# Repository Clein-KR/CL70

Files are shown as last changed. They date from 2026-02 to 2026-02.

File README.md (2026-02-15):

# CL70

<br />

CL70은 제가 자작을 시도하며 처음 만들었던 키보드입니다.

아무것도 모르는 채로 시작하여 겪어야 했던 수 많은 시행 착오를 다른 분들은 최대한 줄였으면 하는 마음에 해당 키보드를 리메이크 하는 내용으로 [나만의 커스텀 커스텀 키보드 만들기 시리즈](https://www.notion.so/clein-kr/27f2e6fbea69806facf0daf639f351d5)를 노션에 연재해 두었으니 자작 키보드에 관심이 있으신 분들은 한 번 읽어 보시는 것을 추천 드립니다.

<br />
<br />

**Silver Top**

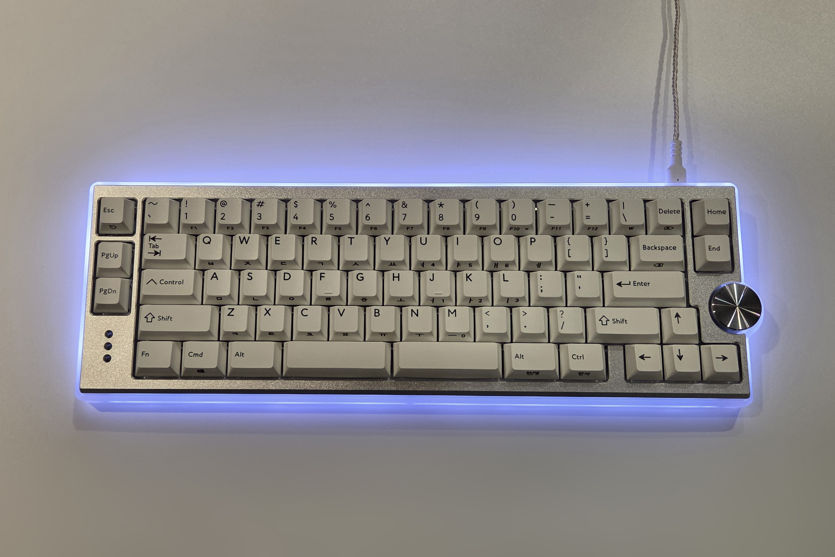
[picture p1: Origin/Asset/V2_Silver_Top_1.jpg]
V2 Silver Top 1

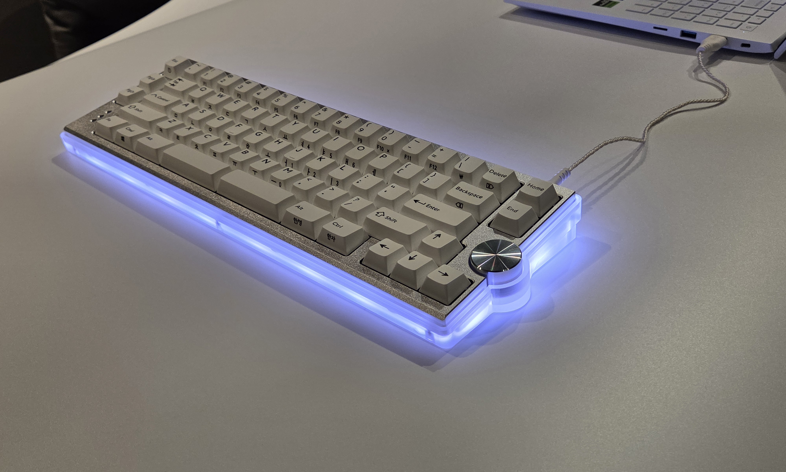
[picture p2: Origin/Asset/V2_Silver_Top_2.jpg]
V2 Silver Top 2


<br />

**Black Top**

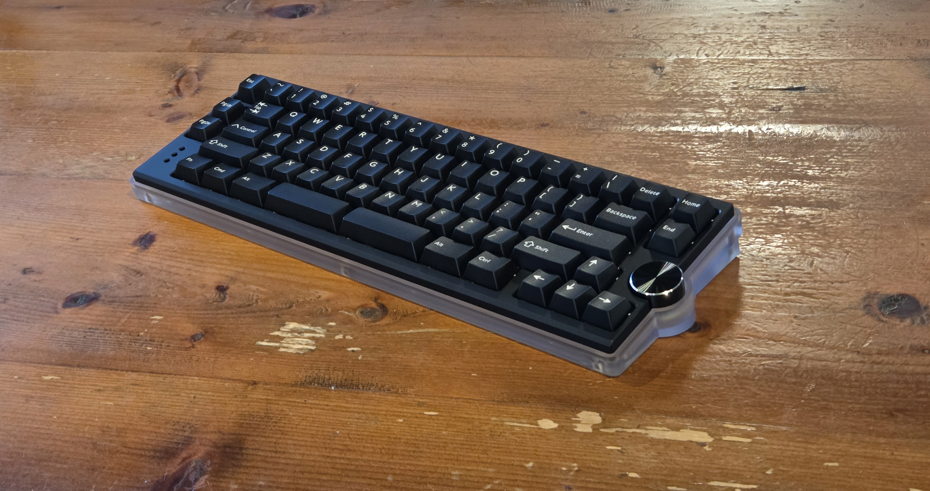
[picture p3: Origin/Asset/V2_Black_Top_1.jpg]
V2 Black Top 1

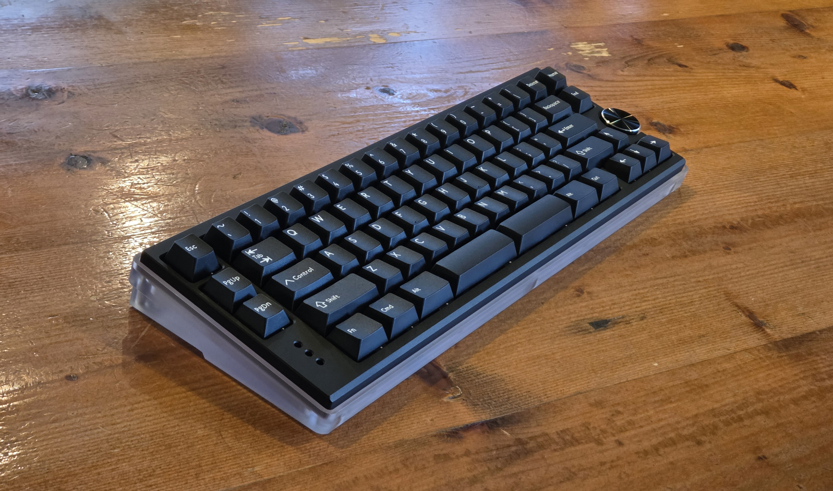
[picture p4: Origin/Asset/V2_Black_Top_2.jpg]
V2 Black Top 2


<br />
<br />

## Licence

<br />

작업물에 대한 영리적 목적의 사용 및 재배포는 허용하지 않으며, 비영리적 활동에만 사용 및 출처를 포함한 재배포를 허용합니다. 또한 작업물에 만약 오류나 문제가 있더라도 원작자는 이에 대해 어떠한 책임도 지지 않음을 미리 밝힙니다. 라이선스 전문은 [여기](./LICENCE)에서 보실 수 있습니다.

<br />
<br />

© 2026 [Clein](https://github.com/Clein-KR) All Rights Reserved. Licensed under [CC BY-NC 4.0](https://creativecommons.org/licenses/by-nc/4.0/)

<br />

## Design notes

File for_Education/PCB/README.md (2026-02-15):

# CL70 PCB for Education

<br />

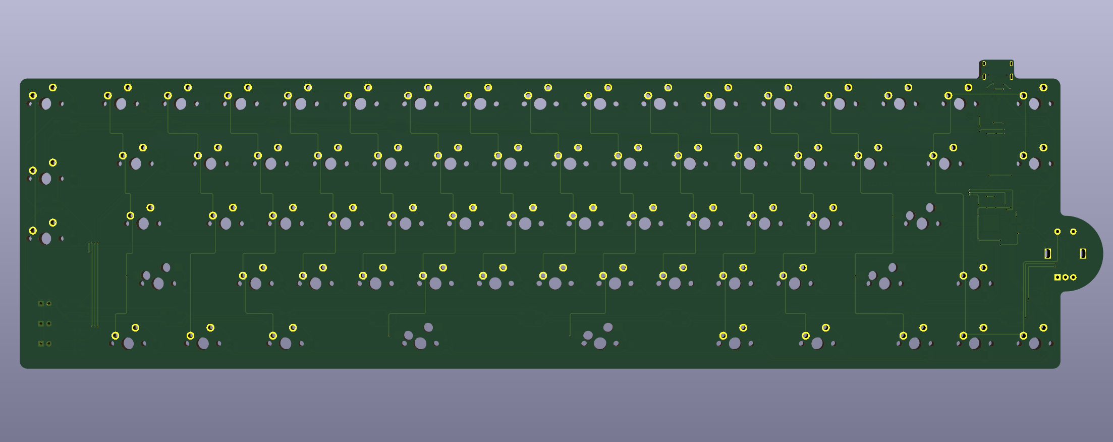
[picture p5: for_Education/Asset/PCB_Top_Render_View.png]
PCB Render Top View

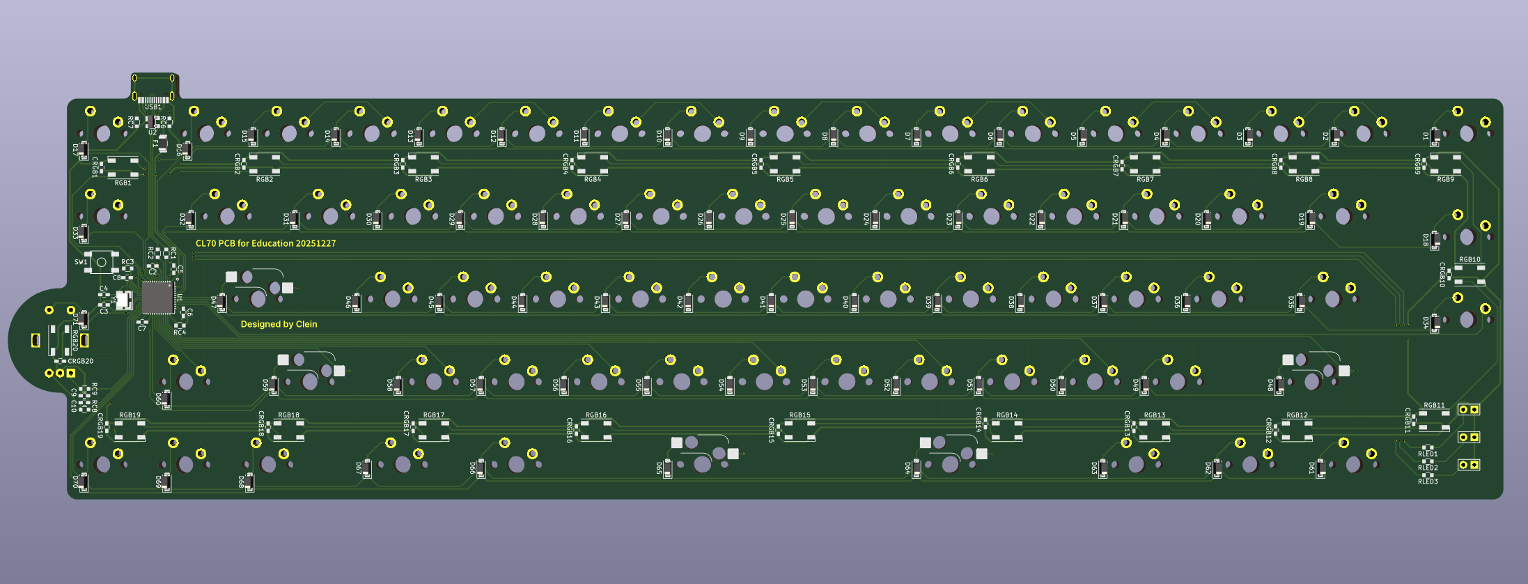
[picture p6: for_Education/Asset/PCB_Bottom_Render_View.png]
PCB Render Bottom View


<br />
<br />

## Licence

<br />

해당 프로젝트는 [ai03](https://github.com/ai03-2725) 님의 [KBD8X-MKII-PCB](https://github.com/ai03-2725/KBD8X-MKII-PCB) 프로젝트와 [Joe Scotto](https://github.com/joe-scotto) 님의 [ScottoKeebs](https://github.com/joe-scotto/scottokeebs) 프로젝트를 기반으로 만들어졌습니다. 해당 프로젝트를 활용한 수정, 복제, 배포 등의 활동은 저작자 표시와 함께 비영리적인 목적에 한해서만 가능하며, 라이선스 전문은 [여기](./LICENCE)에서 보실 수 있습니다.

<br />



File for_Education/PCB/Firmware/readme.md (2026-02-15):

# clein/cl70/for_education

clein/cl70/for_education

*A short description of the keyboard/project*

* Keyboard Maintainer: [Clein](https://github.com/Clein)
* Hardware Supported: *The PCBs, controllers supported*
* Hardware Availability: *Links to where you can find this hardware*

Make example for this keyboard (after setting up your build environment):

    make clein/cl70/for_education:default

Flashing example for this keyboard:

    make clein/cl70/for_education:default:flash

See the [build environment setup](https://docs.qmk.fm/#/getting_started_build_tools) and the [make instructions](https://docs.qmk.fm/#/getting_started_make_guide) for more information. Brand new to QMK? Start with our [Complete Newbs Guide](https://docs.qmk.fm/#/newbs).

## Bootloader

Enter the bootloader in 3 ways:

* **Bootmagic reset**: Hold down the key at (0,0) in the matrix (usually the top left key or Escape) and plug in the keyboard
* **Physical reset button**: Briefly press the button on the back of the PCB - some may have pads you must short instead
* **Keycode in layout**: Press the key mapped to `QK_BOOT` if it is available

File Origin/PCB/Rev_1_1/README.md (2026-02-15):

# CL70 PCB

<br />

[CL70 PCB Rev 1.0](/Origin/PCB/Rev_1_0/)에서 6u 스페이스바 단일 배열로 변경된 버전입니다. 이외 변경 사항은 없습니다.

<br />

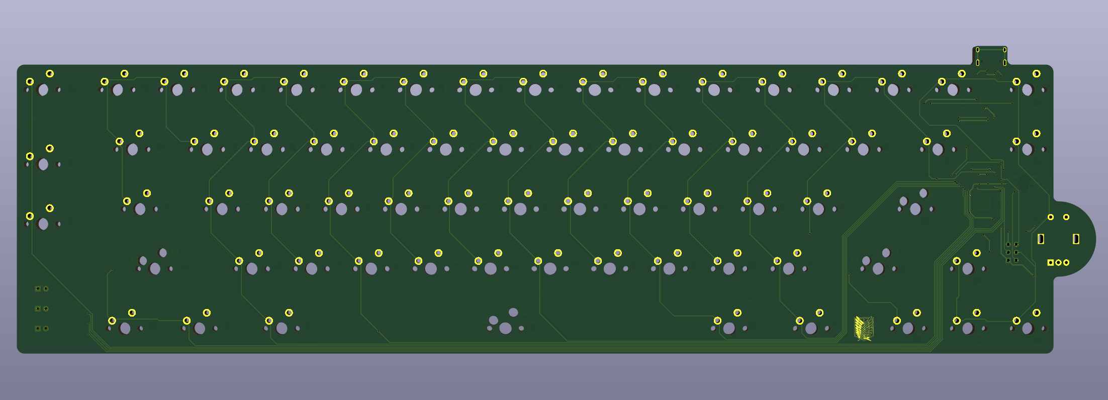
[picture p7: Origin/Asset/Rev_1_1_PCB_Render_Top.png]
PCB Rendering Top View

PCB Rendering Bottom View

<br />
<br />

## Licence

<br />

해당 프로젝트는 [ai03](https://github.com/ai03-2725) 님의 [KBD8X-MKII-PCB](https://github.com/ai03-2725/KBD8X-MKII-PCB) 프로젝트와 [Joe Scotto](https://github.com/joe-scotto) 님의 [ScottoKeebs](https://github.com/joe-scotto/scottokeebs) 프로젝트를 기반으로 만들어졌습니다. 해당 프로젝트를 활용한 수정, 복제, 배포 등의 활동은 저작자 표시와 함께 비영리적인 목적에 한해서만 가능하며, 라이선스 전문은 [여기](./LICENCE)에서 보실 수 있습니다.

<br />



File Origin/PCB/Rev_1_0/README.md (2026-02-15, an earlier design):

# CL70 PCB

<br />

해당 PCB의 프로토타입은 [PCBWay](https://www.pcbway.com/)를 통해 제작되었습니다.

<br />

PCB Rendering Top View
PCB Rendering Bottom View

<br />

PCB Prototype Top View
PCB Prototype Bottom View

<br />

아래는 적용된 옵션입니다.

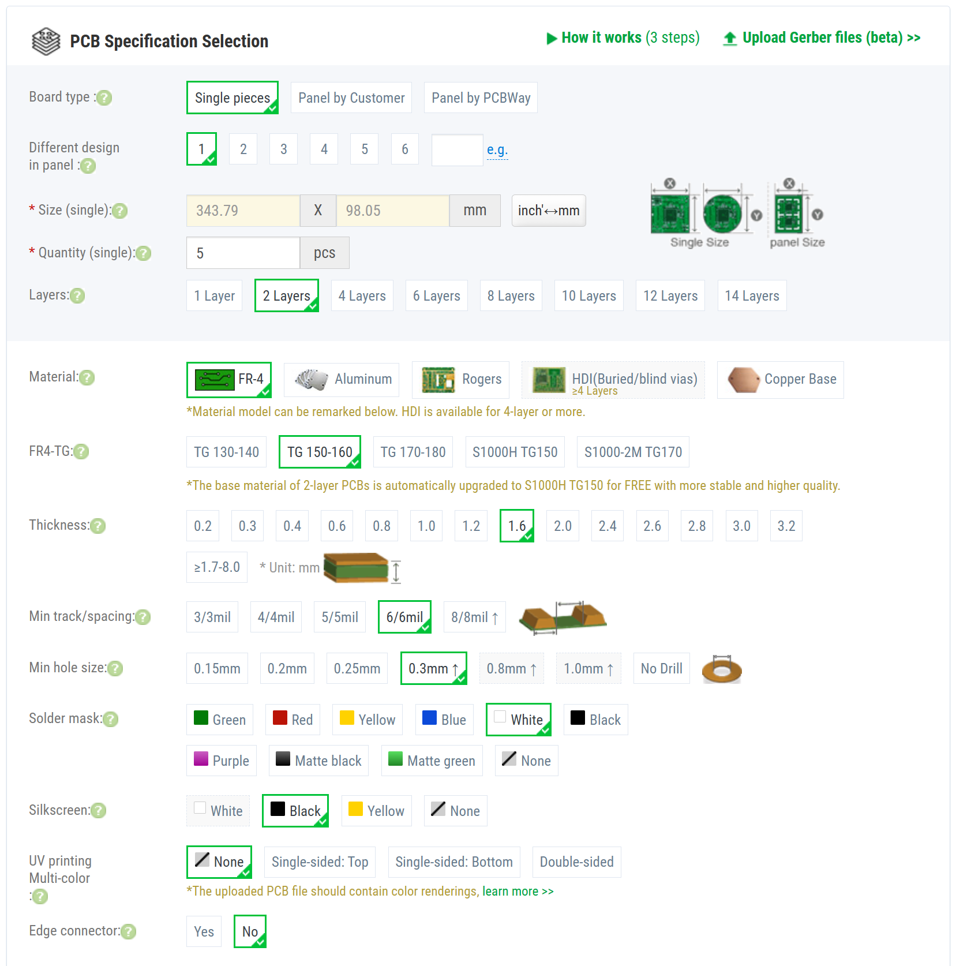
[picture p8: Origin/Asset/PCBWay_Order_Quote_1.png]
Options applied to the PCB prototype 1

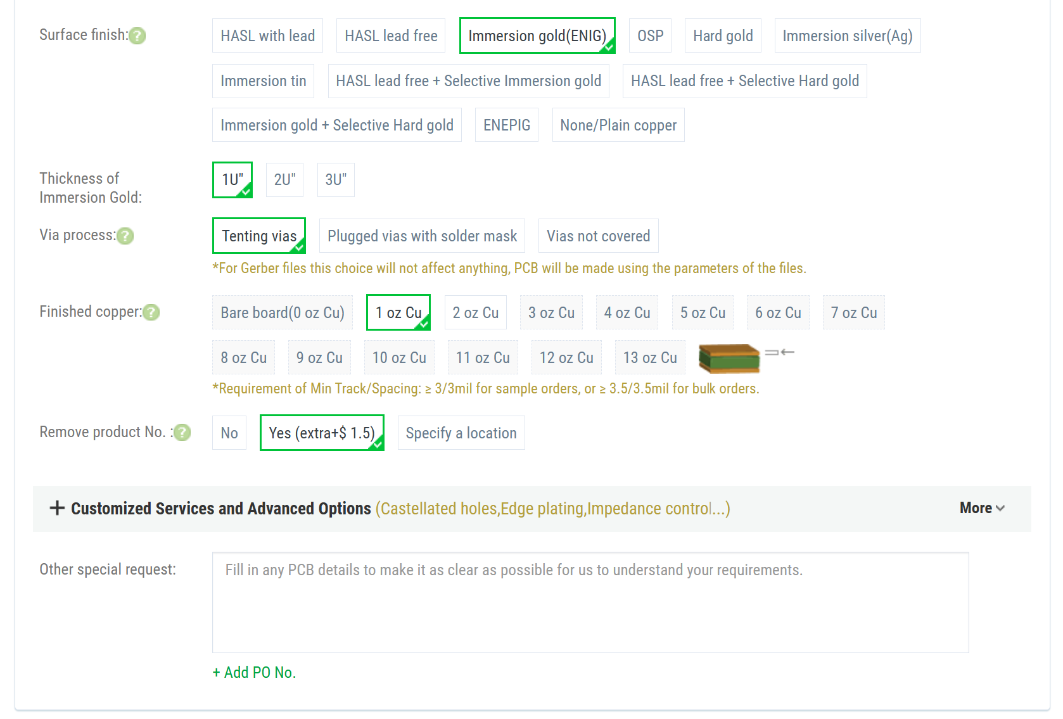
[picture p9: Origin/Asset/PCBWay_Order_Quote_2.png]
Options applied to the PCB prototype 2


<br />
<br />

## Licence

<br />

해당 프로젝트는 [ai03](https://github.com/ai03-2725) 님의 [KBD8X-MKII-PCB](https://github.com/ai03-2725/KBD8X-MKII-PCB) 프로젝트와 [Joe Scotto](https://github.com/joe-scotto) 님의 [ScottoKeebs](https://github.com/joe-scotto/scottokeebs) 프로젝트를 기반으로 만들어졌습니다. 해당 프로젝트를 활용한 수정, 복제, 배포 등의 활동은 저작자 표시와 함께 비영리적인 목적에 한해서만 가능하며, 라이선스 전문은 [여기](./LICENCE)에서 보실 수 있습니다.

<br />



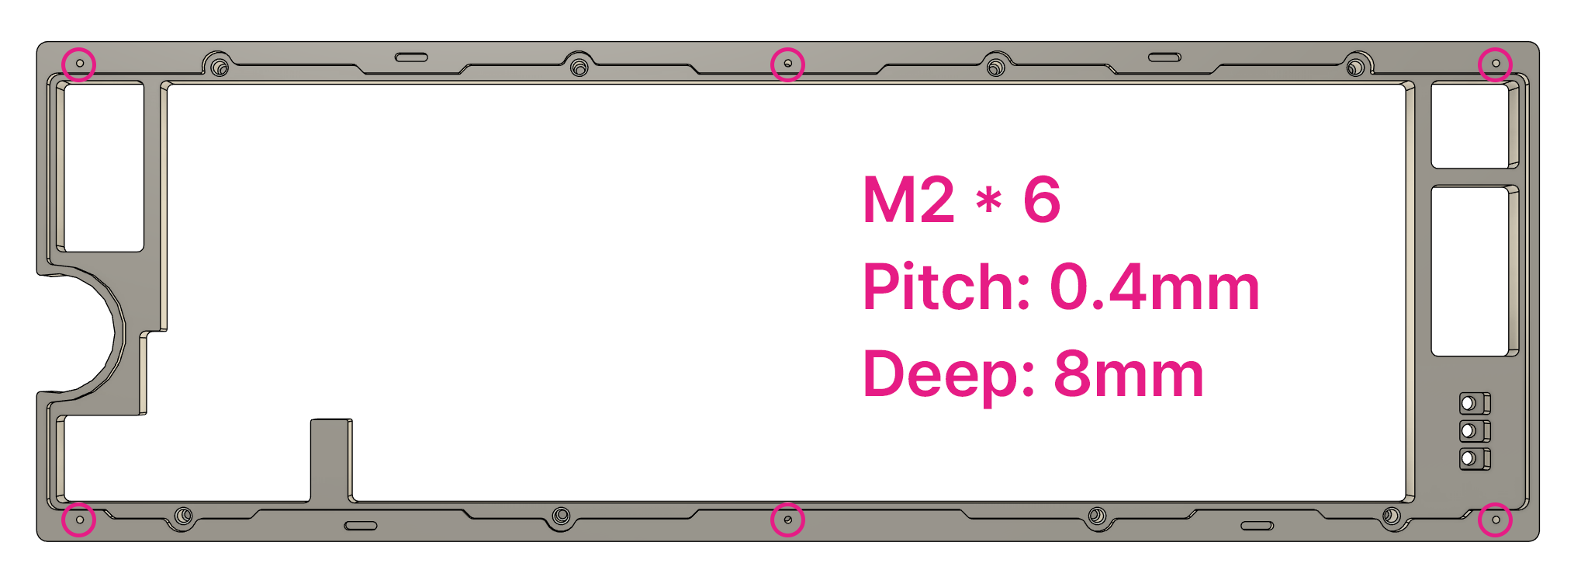
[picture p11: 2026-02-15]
for_Education/Case/CL70_EDU_TopCase_TappedHole.png

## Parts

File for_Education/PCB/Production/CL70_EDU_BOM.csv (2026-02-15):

Item # | *Designator | *Qty | Manufacturer | *Mfg Part # | LCSC Part # | Description / Value | *Package/Footprint | Pins | Your Instructions / Notes
1 | C6,C7,C8,CRGB1,CRGB2,CRGB3,CRGB4,CRGB5,CRGB6,CRGB7,CRGB8,CRGB9,CRGB10,CRGB11,CRGB12,CRGB13,CRGB14,CRGB15,CRGB16,CRGB17,CRGB18,CRGB19,CRGB20 | 23 | YAGEO | CC0603JRX7R7BB104 | C109474 | Capacitor, Ceramic, 0603 | C_0603 | 2 | 0.1uF 20% ≥15V X5R/X7R
2 | C5 | 1 | HRE | CGA0603X5R106M160JT | C6119814 | Capacitor, Ceramic, 0603 | C_0603 | 2 | 10uF 20% ≥15V X5R/X7R
3 | C2 | 1 | HRE | CGA0603X5R105K160JT | C6119849 | Capacitor, Ceramic, 0603 | C_0603 | 2 | 1uF 20% ≥15V X5R/X7R
4 | C3,C4 | 2 | KEMET | C0603C220J4GAC7867 | C561800 | Capacitor, Ceramic, 0603 | C_0603 | 2 | 22pF 5% ≥15V C0G
5 | D1,D2,D3,D4,D5,D6,D7,D8,D9,D10,D11,D12,D13,D14,D15,D16,D17,D18,D19,D20,D21,D22,D23,D24,D25,D26,D27,D28,D29,D30,D31,D32,D33,D34,D35,D36,D37,D38,D39,D40,D41,D42,D43,D44,D45,D46,D47,D48,D49,D50,D51,D52,D53,D54,D55,D56,D57,D58,D59,D60,D61,D62,D63,D64,D65,D66,D67,D68,D69,D70,D71 | 71 | Slkor(SLKORMICRO Elec.) | 1N4148W | C444720 | Diode, SOD-123 | D_SOD-123 | 2 | Generic
6 | F1 | 1 | BHFUSE | BSMD1206-050-16V | C883124 | Polyfuse, 1206 | Fuse_SMD1206_Wave | 2 | 500mA ≥15V 500mA_Hold 1A_Trip
7 | RC4,RLED1,RLED2,RLED3 | 4 | YAGEO | RC0603FR-071KL | C22548 | Resistor, Generic, 0603 | R_0603 | 2 | 1k 1%
8 | RC3,RC8,RC9 | 3 | YAGEO | RC0603FR-0710KL | C98220 | Resistor, Generic, 0603 | R_0603 | 2 | 10k 1%
9 | RC1,RC2 | 2 | YAGEO | RC0603FR-0722RL | C107701 | Resistor, Generic, 0603 | R_0603 | 2 | 22 1%
10 | RC6,RC7 | 2 | YAGEO | RC0603FR-075K1L | C105580 | Resistor, Generic, 0603 | R_0603 | 2 | 5.1k 1%
11 | RGB1,RGB2,RGB3,RGB4,RGB5,RGB6,RGB7,RGB8,RGB9,RGB10,RGB11,RGB12,RGB13,RGB14,RGB15,RGB16,RGB17,RGB18,RGB19,RGB20 | 20 | Worldsemi | WS2812B-V5/W | C2874885 | RGB LED, 5050 | LED_WS2812B-PLCC4 | 4 | WS2812B
12 | SW1 | 1 | ALPSALPINE | SKQGABE010 | C115351 | Push button | SKQG-1155865 | 4 | SMT 5.2 x 5.2 x 1.5mm
13 | U1 | 1 | MICROCHIP | ATMEGA32U4-MU | C112161 | ATmega32U4-MU | QFN-44-1EP_7x7mm_Pitch0.5mm | 45 | ATmega32U4-MU
14 | U2 | 1 | Nexperia | PRTR5V0U2X,215 | C12333 | ESD Protection IC | SOT143B | 4 | PRTR5V0U2X
15 | USB1 | 1 | Korean Hroparts Elec | TYPE-C-31-M-12 | C165948 | USB Type-C Connector | HRO-TYPE-C-31-M-12-Assembly | 16 | HRO-TYPE-C-31-M-12
16 | Y1 | 1 | Huiyuan crystal | HY16MSMD3225OB1R30 | C7275098 | Crystal, 3.2 x 2.5mm (3225-4) | Crystal_SMD_3225-4pin_3.2x2.5mm | 4 | 16MHz

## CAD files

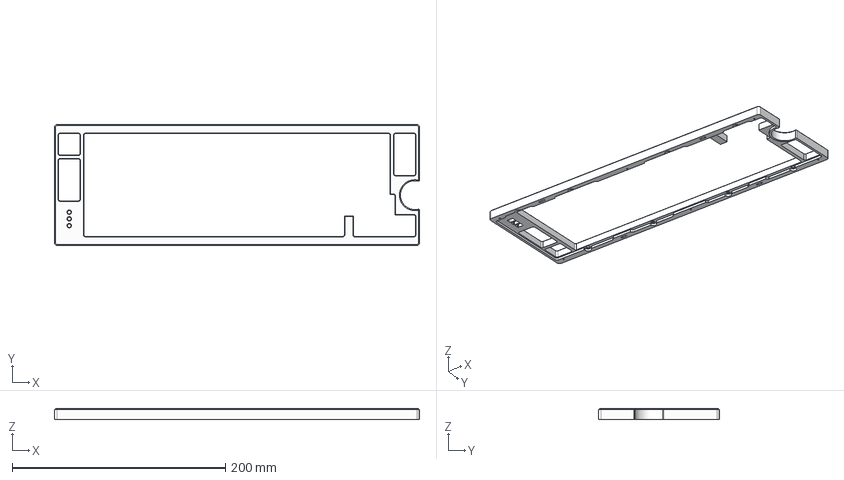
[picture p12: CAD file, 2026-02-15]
for_Education/Case/CL70_EDU_TopCase.step
342.0 x 113.5 x 10.0 mm

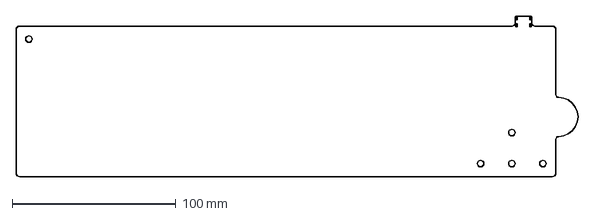
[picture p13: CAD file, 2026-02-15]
for_Education/PCB/Guide/PCB_OUTLINE.dxf
344.3 x 98.1 mm

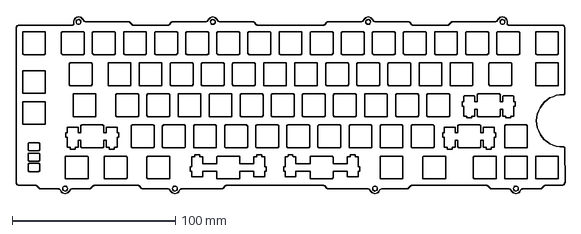
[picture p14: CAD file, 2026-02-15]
for_Education/Plate/CL70_Plate.dxf
336.3 x 108.5 mm

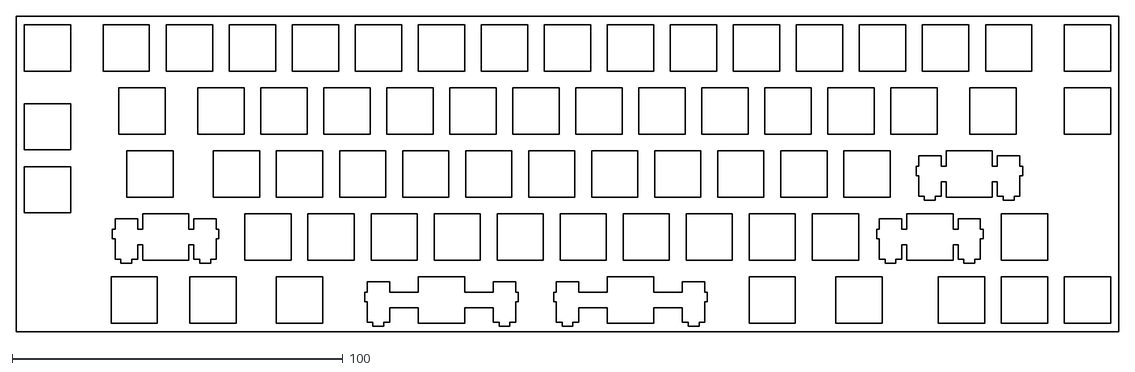
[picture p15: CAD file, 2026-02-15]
for_Education/Plate/References/builder.swillkb.com.dxf
333.4 x 95.2

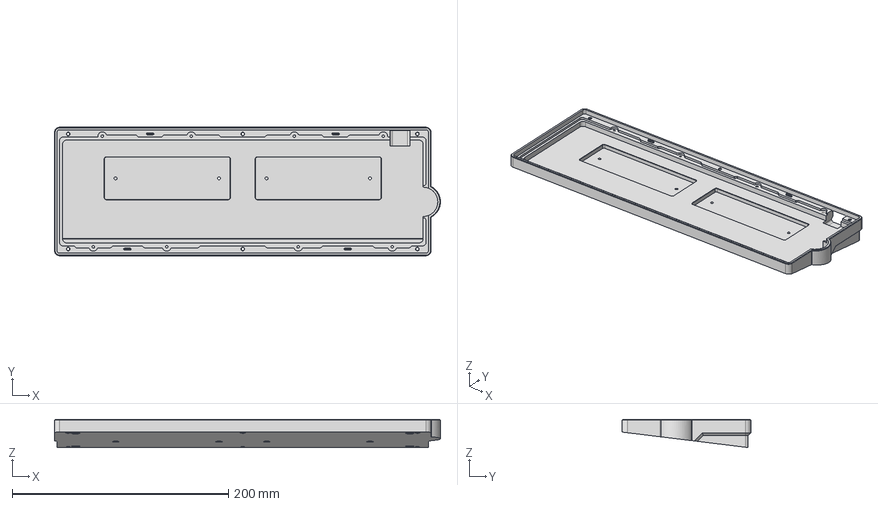
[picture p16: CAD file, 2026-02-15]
Origin/Case/CL70_BottomCase_V2.step
356.7 x 118.9 x 26.0 mm

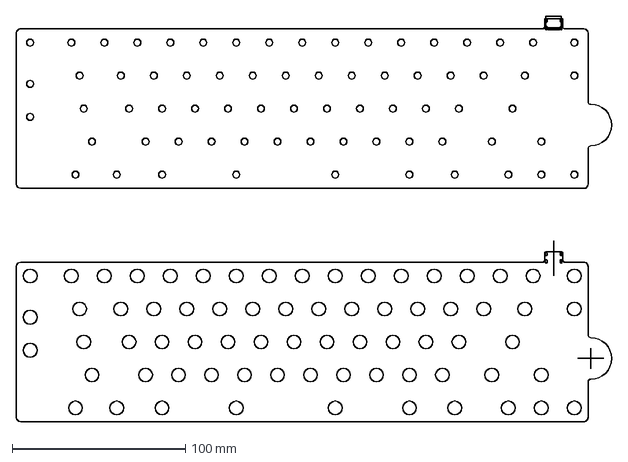
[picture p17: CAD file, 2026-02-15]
Origin/PCB/Rev_1_1/Guide/PCB_OUTLINE.dxf
343.8 x 234.1 mm

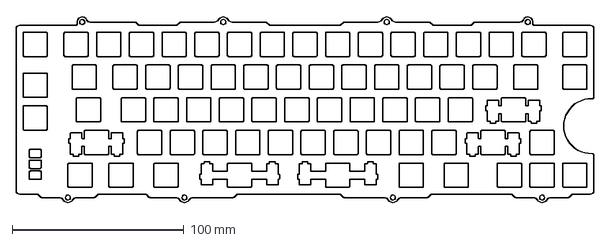
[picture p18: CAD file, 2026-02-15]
Origin/Plate/CL70_Plate_3u_Split.dxf
336.5 x 108.5 mm

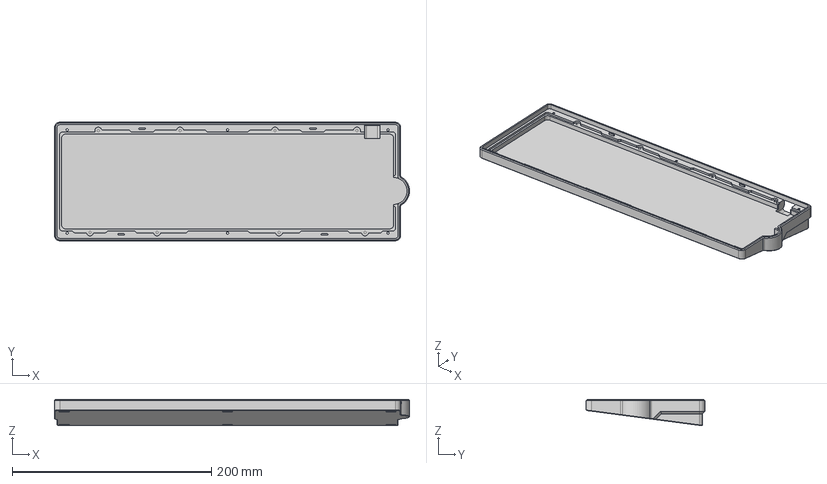
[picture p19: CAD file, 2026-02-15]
for_Education/Case/CL70_EDU_BottomCase.step
356.4 x 119.1 x 26.5 mm

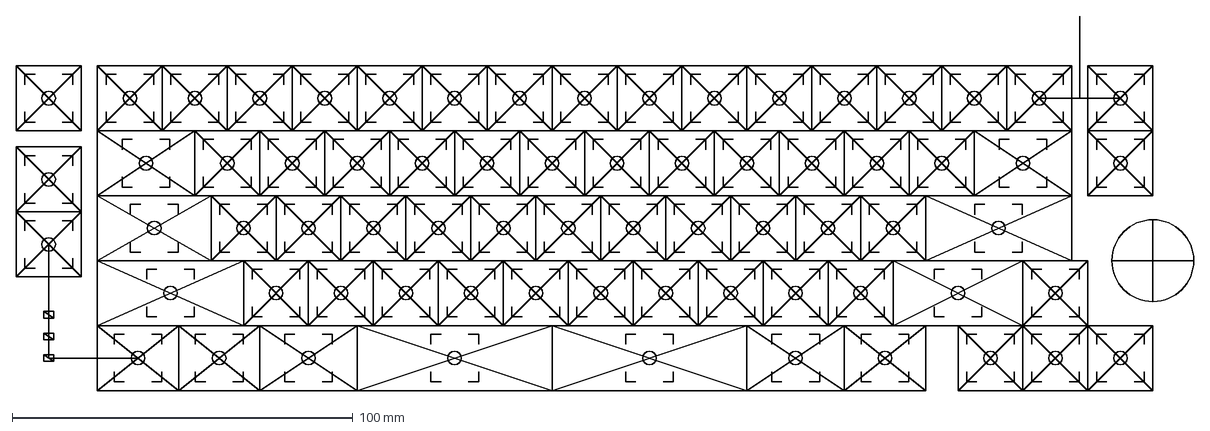
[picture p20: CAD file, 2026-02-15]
for_Education/PCB/Guide/PCB_GUIDELINE.dxf
345.4 x 109.7 mm

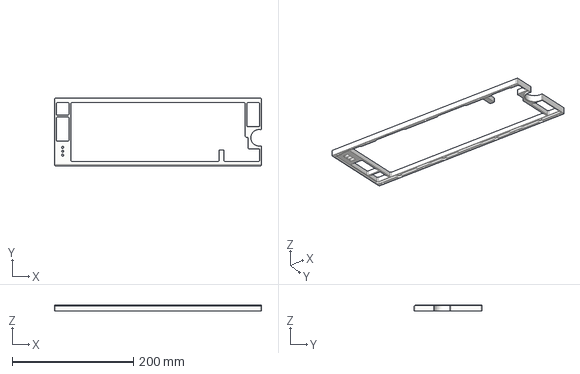
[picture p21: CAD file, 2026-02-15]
Origin/Case/CL70_TopCase_V2.step
341.4 x 112.3 x 10.0 mm

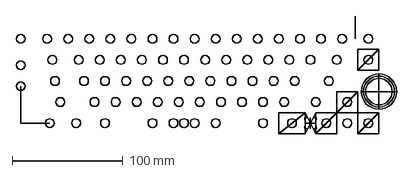
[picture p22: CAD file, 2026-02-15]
Origin/PCB/Rev_1_1/Guide/PCB_GUIDELINE.dxf
343.9 x 106.1 mm

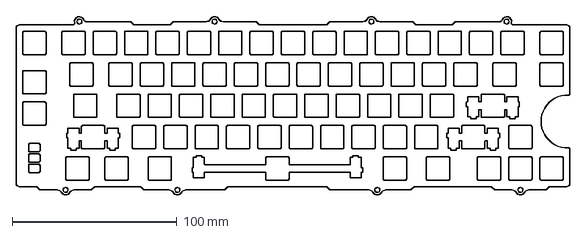
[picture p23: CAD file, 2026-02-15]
Origin/Plate/CL70_Plate_6u.dxf
336.5 x 108.5 mm

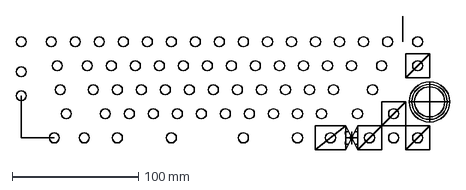
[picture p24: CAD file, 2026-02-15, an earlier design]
Origin/PCB/Rev_1_0/Guide/PCB_GUIDELINE.dxf
343.9 x 106.1 mm

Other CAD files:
Origin/Case/CL70_BottomCase_V2_InsertNuts.step
Origin/Case/CL70_TopCase_V2_TappedHole.step
Origin/Case/CL70_BottomCase_V2_TappedHole.step
Origin/Case/CL70_BottomCase_V2_NonWeight.step
Origin/PCB/Rev_1_0/Guide/PCB_GUIDELINE.dwg
Origin/PCB/Rev_1_0/Guide/PCB_OUTLINE.dwg
Origin/PCB/Rev_1_1/Guide/PCB_GUIDELINE.dwg
Origin/PCB/Rev_1_1/Guide/PCB_OUTLINE.dwg
Origin/Plate/CL70_Plate_3u_Split.dwg
Origin/Plate/CL70_Plate_6u.dwg
for_Education/Case/CL70_EDU.f3d
for_Education/PCB/Guide/PCB_GUIDELINE.dwg
for_Education/PCB/Guide/PCB_OUTLINE.dwg
for_Education/Plate/CL70_Plate.dwg

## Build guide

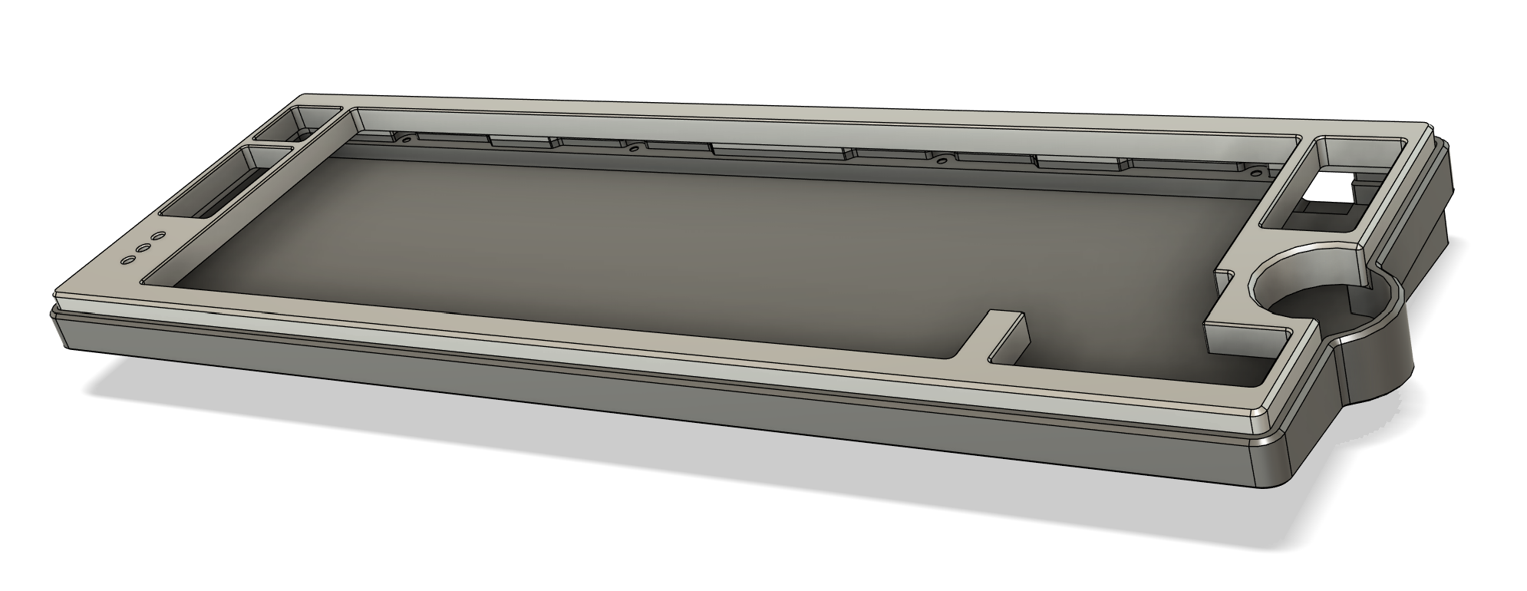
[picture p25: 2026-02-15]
for_Education/Case/CL70_EDU_AssemblyTest_1.png

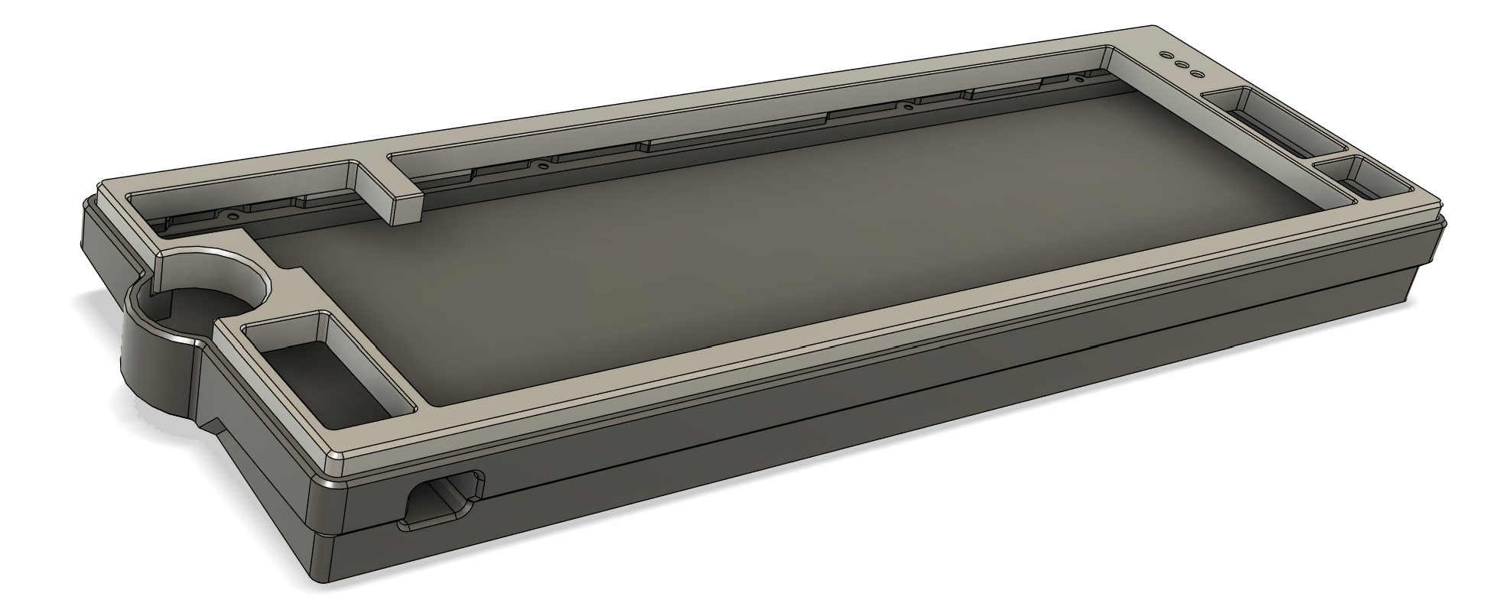
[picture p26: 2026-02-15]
for_Education/Case/CL70_EDU_AssemblyTest_3.png

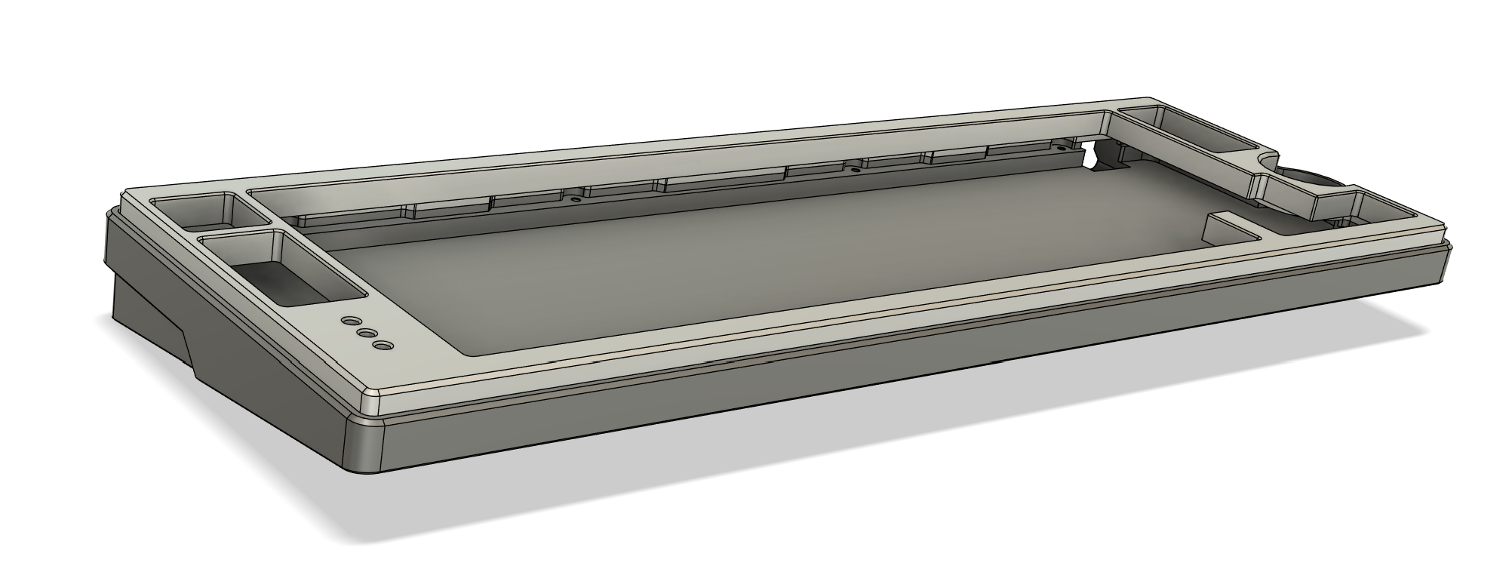
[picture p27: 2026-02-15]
for_Education/Case/CL70_EDU_AssemblyTest_2.png

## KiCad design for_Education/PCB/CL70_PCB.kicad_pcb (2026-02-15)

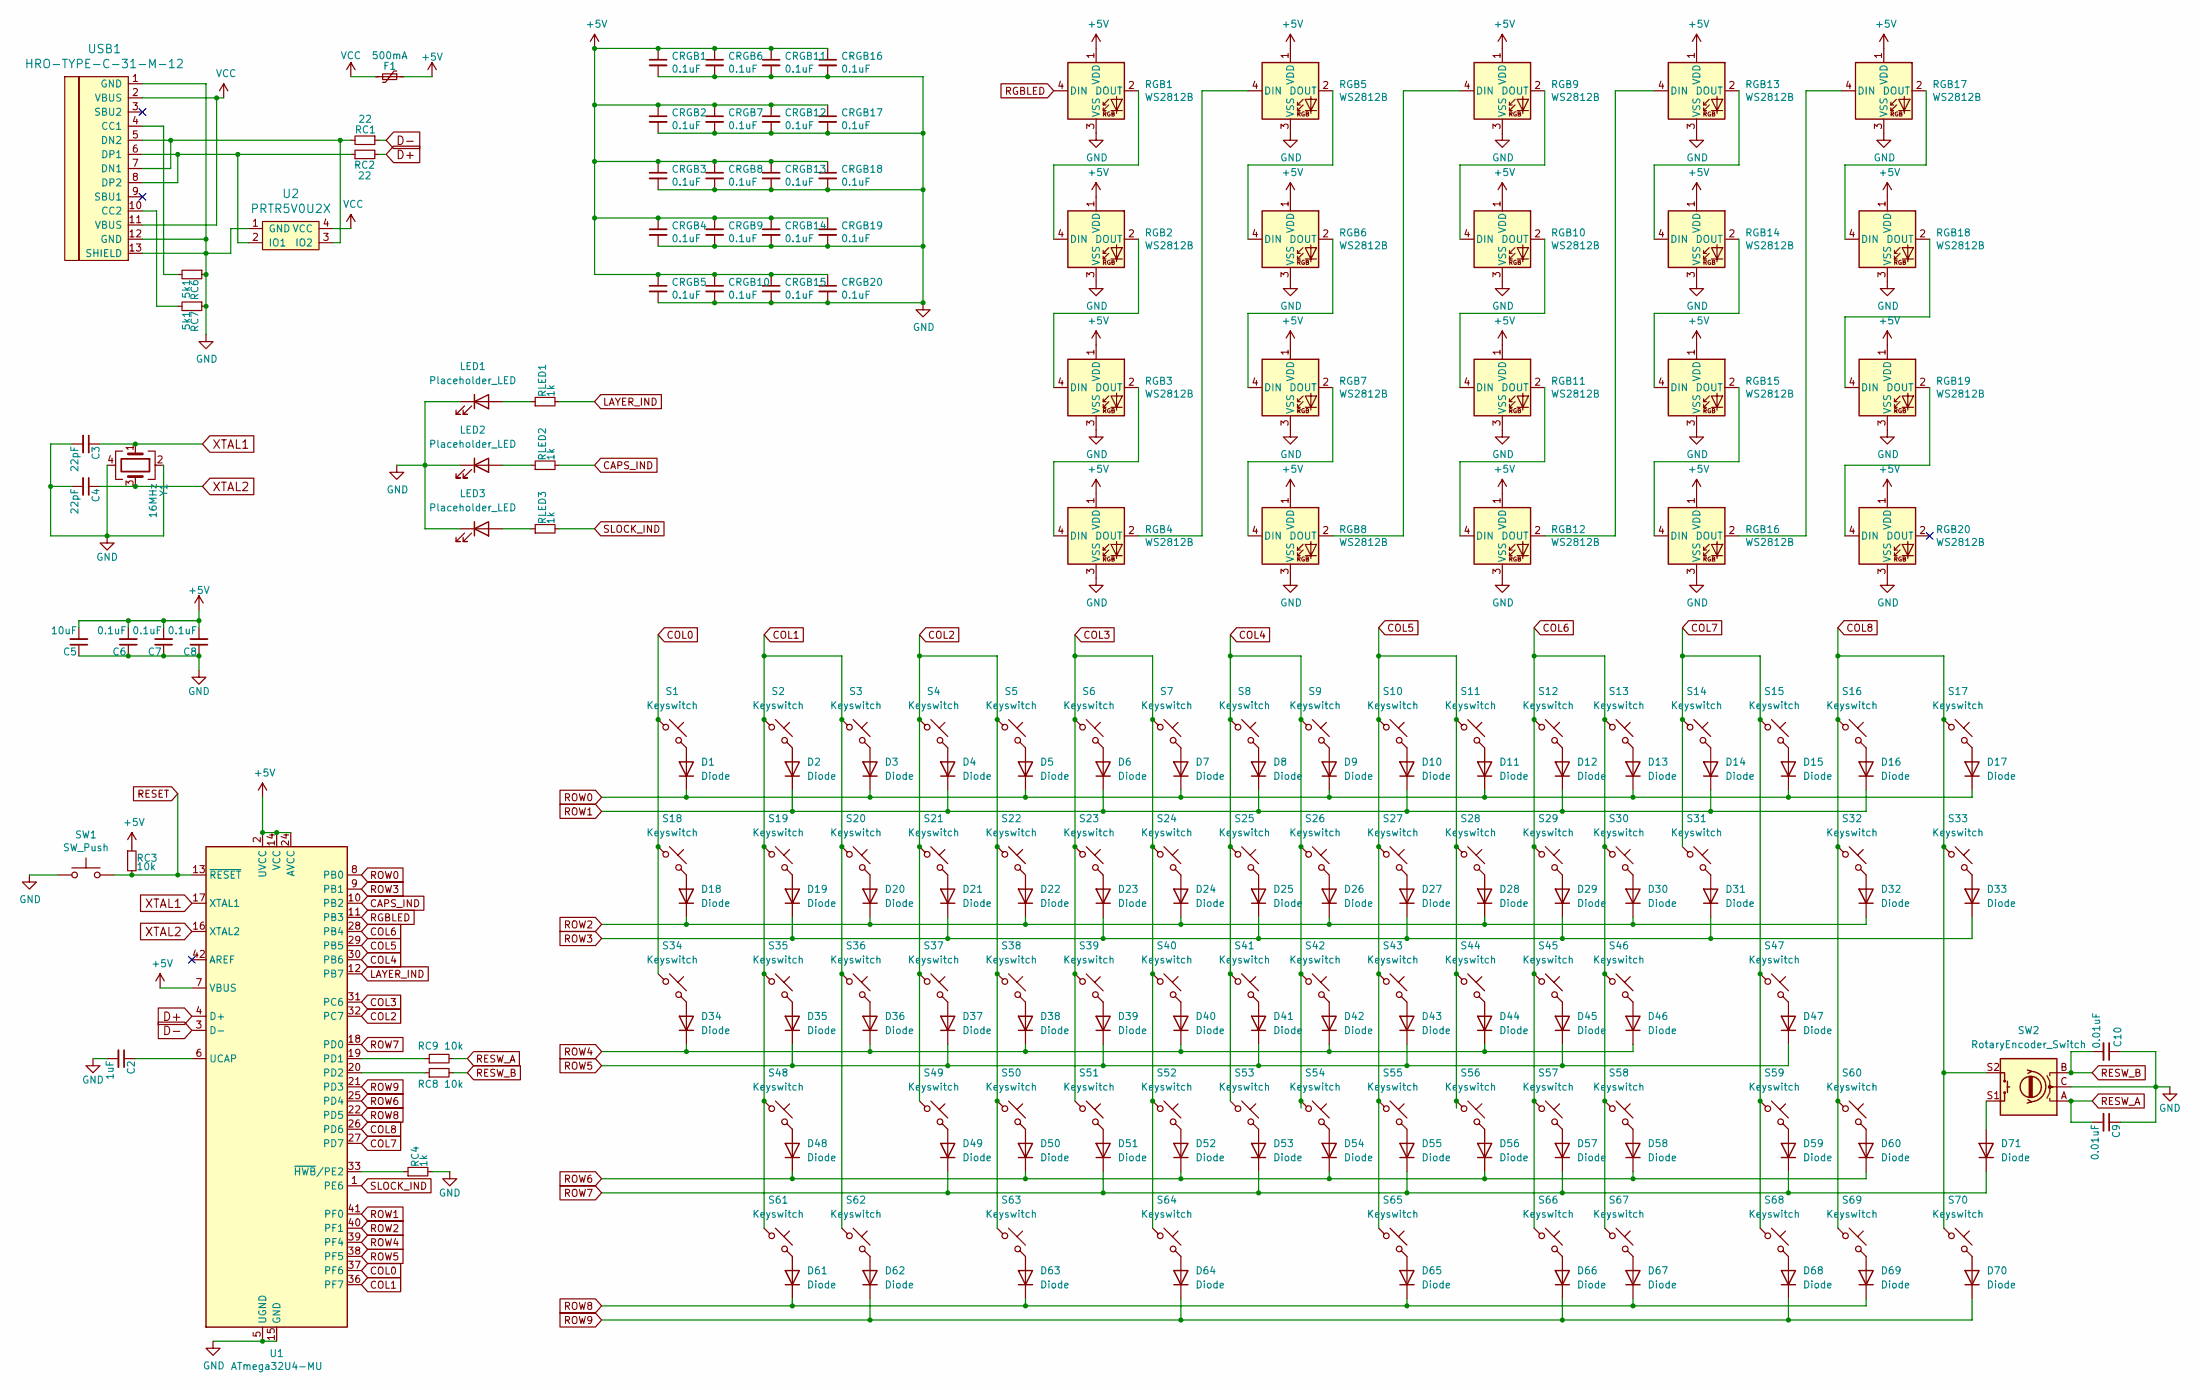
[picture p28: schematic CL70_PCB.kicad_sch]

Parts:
C2: 1uF; C_0603
C3, C4: 22pF; C_0603
C5: 10uF; C_0603
C6, C7, C8: 0.1uF; C_0603
C9, C10: 0.01uF; C_0603
CRGB1, CRGB2, CRGB3, CRGB4, CRGB5, CRGB6, CRGB7, CRGB8, CRGB9, CRGB10, CRGB11, CRGB12, CRGB13, CRGB14, CRGB15, CRGB16, CRGB17, CRGB18, CRGB19, CRGB20: 0.1uF; C_0603
D1, D2, D3, D4, D5, D6, D7, D8, D9, D10, D11, D12, D13, D14, D15, D16, D17, D18, D19, D20, D21, D22, D23, D24, D25, D26, D27, D28, D29, D30, D31, D32, D33, D34, D35, D36, D37, D38, D39, D40, D41, D42, D43, D44, D45, D46, D47, D48, D49, D50, D51, D52, D53, D54, D55, D56, D57, D58, D59, D60, D61, D62, D63, D64, D65, D66, D67, D68, D69, D70, D71: Diode; D_SOD-123
F1: 500mA; Fuse_1206_3216Metric
LED1, LED2, LED3: Placeholder_LED; LED_D3.0mm-Pretty
RC1, RC2: 22; R_0603
RC3, RC8, RC9: 10k; R_0603
RC4: 1k; R_0603
RC6, RC7: 5k1; R_0603
RGB1, RGB2, RGB3, RGB4, RGB5, RGB6, RGB7, RGB8, RGB9, RGB10, RGB11, RGB12, RGB13, RGB14, RGB15, RGB16, RGB17, RGB18, RGB19, RGB20: WS2812B; LED_WS2812B-PLCC4
RLED1, RLED2, RLED3: 1k; R_0603
S1, S2, S3, S4, S5, S6, S7, S8, S9, S10, S11, S12, S13, S14, S15, S16, S17, S18, S20, S21, S22, S23, S24, S25, S26, S27, S28, S29, S30, S31, S33, S34, S36, S37, S38, S39, S40, S41, S42, S43, S44, S45, S46, S49, S50, S51, S52, S53, S54, S55, S56, S57, S58, S60, S68, S69, S70: Keyswitch; MX_PCB_1.00u
S19, S32, S63, S66: Keyswitch; MX_PCB_1.50u
S35: Keyswitch; MX_PCB_1.75u
S47, S48: Keyswitch; Hotswap_MX_2.25u
S59: Keyswitch; Hotswap_MX_2.00u
S61, S62, S67: Keyswitch; MX_PCB_1.25u
S64, S65: Keyswitch; Hotswap_MX_3.00u
SW1: SW_Push; SKQG-1155865
SW2: RotaryEncoder_Switch; RotaryEncoder_Alps_EC11E-Switch_Vertical_H20mm
U1: ATmega32U4-MU; QFN-44-1EP_7x7mm_Pitch0.5mm
U2: PRTR5V0U2X; SOT143B
USB1: HRO-TYPE-C-31-M-12; HRO-TYPE-C-31-M-12-Assembly
Y1: 16MHz; Crystal_SMD_3225-4pin_3.2x2.5mm

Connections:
+5V: C5.2, C6.2, C7.2, C8.2, CRGB1.1, CRGB2.1, CRGB3.1, CRGB4.1, CRGB5.1, CRGB6.1, CRGB7.1, CRGB8.1, CRGB9.1, CRGB10.1, CRGB11.1, CRGB12.1, CRGB13.1, CRGB14.1, CRGB15.1, CRGB16.1, CRGB17.1, CRGB18.1, CRGB19.1, CRGB20.1, F1.1, RC3.1, RGB1.1 (VDD), RGB2.1 (VDD), RGB3.1 (VDD), RGB4.1 (VDD), RGB5.1 (VDD), RGB6.1 (VDD), RGB7.1 (VDD), RGB8.1 (VDD), RGB9.1 (VDD), RGB10.1 (VDD), RGB11.1 (VDD), RGB12.1 (VDD), RGB13.1 (VDD), RGB14.1 (VDD), RGB15.1 (VDD), RGB16.1 (VDD), RGB17.1 (VDD), RGB18.1 (VDD), RGB19.1 (VDD), RGB20.1 (VDD), U1.2 (UVCC), U1.7 (VBUS), U1.14 (VCC), U1.24 (AVCC), U1.34 (VCC), U1.44 (AVCC)
CAPS_IND: RLED2.2, U1.10 (PB2)
COL0: S1.1, S18.1, S34.1, U1.37 (PF6)
COL1: S2.1, S3.1, S19.1, S20.1, S35.1, S36.1, S48.1, S61.1, S62.1, U1.36 (PF7)
COL2: S4.1, S5.1, S21.1, S22.1, S37.1, S38.1, S49.1, S50.1, S63.1, U1.32 (PC7)
COL3: S6.1, S7.1, S23.1, S24.1, S39.1, S40.1, S51.1, S52.1, S64.1, U1.31 (PC6)
COL4: S8.1, S9.1, S25.1, S26.1, S41.1, S42.1, S53.1, S54.1, U1.30 (PB6)
COL5: S10.1, S11.1, S27.1, S28.1, S43.1, S44.1, S55.1, S56.1, S65.1, U1.29 (PB5)
COL6: S12.1, S13.1, S29.1, S30.1, S45.1, S46.1, S57.1, S58.1, S66.1, S67.1, U1.28 (PB4)
COL7: S14.1, S15.1, S31.1, S47.1, S59.1, S68.1, U1.27 (PD7)
COL8: S16.1, S17.1, S32.1, S33.1, S60.1, S69.1, S70.1, SW2.S2, U1.26 (PD6)
D+: RC2.2, U1.4 (D+)
D-: RC1.1, U1.3 (D-)
GND: C2.2, C3.2, C4.2, C5.1, C6.1, C7.1, C8.1, C9.1, C10.1, CRGB1.2, CRGB2.2, CRGB3.2, CRGB4.2, CRGB5.2, CRGB6.2, CRGB7.2, CRGB8.2, CRGB9.2, CRGB10.2, CRGB11.2, CRGB12.2, CRGB13.2, CRGB14.2, CRGB15.2, CRGB16.2, CRGB17.2, CRGB18.2, CRGB19.2, CRGB20.2, LED1.1 (K), LED2.1 (K), LED3.1 (K), RC4.2, RC6.1, RC7.1, RGB1.3 (VSS), RGB2.3 (VSS), RGB3.3 (VSS), RGB4.3 (VSS), RGB5.3 (VSS), RGB6.3 (VSS), RGB7.3 (VSS), RGB8.3 (VSS), RGB9.3 (VSS), RGB10.3 (VSS), RGB11.3 (VSS), RGB12.3 (VSS), RGB13.3 (VSS), RGB14.3 (VSS), RGB15.3 (VSS), RGB16.3 (VSS), RGB17.3 (VSS), RGB18.3 (VSS), RGB19.3 (VSS), RGB20.3 (VSS), SW1.1, SW2.C, U1.5 (UGND), U1.15 (GND), U1.23 (GND), U1.35 (GND), U1.43 (GND), U1.45 (GND), U2.1 (GND), USB1.1 (GND), USB1.12 (GND), USB1.13 (SHIELD), Y1.2, Y1.4
LAYER_IND: RLED1.2, U1.12 (PB7)
unnamed: D1.2 (A), S1.2
unnamed: D2.2 (A), S2.2
unnamed: D3.2 (A), S3.2
unnamed: D4.2 (A), S4.2
unnamed: D5.2 (A), S5.2
unnamed: D6.2 (A), S6.2
unnamed: D7.2 (A), S7.2
unnamed: D8.2 (A), S8.2
unnamed: D9.2 (A), S9.2
unnamed: D10.2 (A), S10.2
unnamed: D11.2 (A), S11.2
unnamed: D12.2 (A), S12.2
unnamed: D13.2 (A), S13.2
unnamed: D14.2 (A), S14.2
unnamed: D15.2 (A), S15.2
unnamed: D16.2 (A), S16.2
unnamed: D17.2 (A), S17.2
unnamed: D18.2 (A), S18.2
unnamed: D19.2 (A), S19.2
unnamed: D20.2 (A), S20.2
unnamed: D21.2 (A), S21.2
unnamed: D22.2 (A), S22.2
unnamed: D23.2 (A), S23.2
unnamed: D24.2 (A), S24.2
unnamed: D25.2 (A), S25.2
unnamed: D26.2 (A), S26.2
unnamed: D27.2 (A), S27.2
unnamed: D28.2 (A), S28.2
unnamed: D29.2 (A), S29.2
unnamed: D30.2 (A), S30.2
unnamed: D31.2 (A), S31.2
unnamed: D32.2 (A), S32.2
unnamed: D33.2 (A), S33.2
unnamed: D34.2 (A), S34.2
unnamed: D35.2 (A), S35.2
unnamed: D36.2 (A), S36.2
unnamed: D37.2 (A), S37.2
unnamed: D38.2 (A), S38.2
unnamed: D39.2 (A), S39.2
unnamed: D40.2 (A), S40.2
unnamed: D41.2 (A), S41.2
unnamed: D42.2 (A), S42.2
unnamed: D43.2 (A), S43.2
unnamed: D44.2 (A), S44.2
unnamed: D45.2 (A), S45.2
unnamed: D46.2 (A), S46.2
unnamed: D47.2 (A), S47.2
unnamed: D48.2 (A), S48.2
unnamed: D49.2 (A), S49.2
unnamed: D50.2 (A), S50.2
unnamed: D51.2 (A), S51.2
unnamed: D52.2 (A), S52.2
unnamed: D53.2 (A), S53.2
unnamed: D54.2 (A), S54.2
unnamed: D55.2 (A), S55.2
unnamed: D56.2 (A), S56.2
unnamed: D57.2 (A), S57.2
unnamed: D58.2 (A), S58.2
unnamed: D59.2 (A), S59.2
unnamed: D60.2 (A), S60.2
unnamed: D61.2 (A), S61.2
unnamed: D62.2 (A), S62.2
unnamed: D63.2 (A), S63.2
unnamed: D64.2 (A), S64.2
unnamed: D65.2 (A), S65.2
unnamed: D66.2 (A), S66.2
unnamed: D67.2 (A), S67.2
unnamed: D68.2 (A), S68.2
unnamed: D69.2 (A), S69.2
unnamed: D70.2 (A), S70.2
unnamed: D71.2 (A), SW2.S1
unnamed: LED1.2 (A), RLED1.1
unnamed: LED2.2 (A), RLED2.1
unnamed: LED3.2 (A), RLED3.1
unnamed: RGB1.2 (DOUT), RGB2.4 (DIN)
unnamed: RGB2.2 (DOUT), RGB3.4 (DIN)
unnamed: RGB3.2 (DOUT), RGB4.4 (DIN)
unnamed: RGB4.2 (DOUT), RGB5.4 (DIN)
unnamed: RGB5.2 (DOUT), RGB6.4 (DIN)
unnamed: RGB6.2 (DOUT), RGB7.4 (DIN)
unnamed: RGB7.2 (DOUT), RGB8.4 (DIN)
unnamed: RGB8.2 (DOUT), RGB9.4 (DIN)
unnamed: RGB9.2 (DOUT), RGB10.4 (DIN)
unnamed: RGB10.2 (DOUT), RGB11.4 (DIN)
unnamed: RGB11.2 (DOUT), RGB12.4 (DIN)
unnamed: RGB12.2 (DOUT), RGB13.4 (DIN)
unnamed: RGB13.2 (DOUT), RGB14.4 (DIN)
unnamed: RGB14.2 (DOUT), RGB15.4 (DIN)
unnamed: RGB15.2 (DOUT), RGB16.4 (DIN)
unnamed: RGB16.2 (DOUT), RGB17.4 (DIN)
unnamed: RGB17.2 (DOUT), RGB18.4 (DIN)
unnamed: RGB18.2 (DOUT), RGB19.4 (DIN)
unnamed: RGB19.2 (DOUT), RGB20.4 (DIN)
unnamed: RC9.1, U1.19 (PD1)
unnamed: RC8.1, U1.20 (PD2)
unnamed: C2.1, U1.6 (UCAP)
unnamed: RC4.1, U1.33 (~HWB/PE2)
unnamed: RC2.1, U2.2 (IO1), USB1.6 (DP1), USB1.8 (DP2)
unnamed: RC1.2, U2.3 (IO2), USB1.5 (DN2), USB1.7 (DN1)
unnamed: RC6.2, USB1.4 (CC1)
unnamed: RC7.2, USB1.10 (CC2)
RESET: RC3.2, SW1.2, U1.13 (~RESET)
RESW_A: C9.2, RC9.2, SW2.A
RESW_B: C10.2, RC8.2, SW2.B
RGBLED: RGB1.4 (DIN), U1.11 (PB3)
ROW0: D1.1 (K), D3.1 (K), D5.1 (K), D7.1 (K), D9.1 (K), D11.1 (K), D13.1 (K), D15.1 (K), D17.1 (K), U1.8 (PB0)
ROW1: D2.1 (K), D4.1 (K), D6.1 (K), D8.1 (K), D10.1 (K), D12.1 (K), D14.1 (K), D16.1 (K), U1.41 (PF0)
ROW2: D18.1 (K), D20.1 (K), D22.1 (K), D24.1 (K), D26.1 (K), D28.1 (K), D30.1 (K), D32.1 (K), U1.40 (PF1)
ROW3: D19.1 (K), D21.1 (K), D23.1 (K), D25.1 (K), D27.1 (K), D29.1 (K), D31.1 (K), D33.1 (K), U1.9 (PB1)
ROW4: D34.1 (K), D36.1 (K), D38.1 (K), D40.1 (K), D42.1 (K), D44.1 (K), D46.1 (K), U1.39 (PF4)
ROW5: D35.1 (K), D37.1 (K), D39.1 (K), D41.1 (K), D43.1 (K), D45.1 (K), D47.1 (K), U1.38 (PF5)
ROW6: D48.1 (K), D50.1 (K), D52.1 (K), D54.1 (K), D56.1 (K), D58.1 (K), D60.1 (K), U1.25 (PD4)
ROW7: D49.1 (K), D51.1 (K), D53.1 (K), D55.1 (K), D57.1 (K), D59.1 (K), D71.1 (K), U1.18 (PD0)
ROW8: D61.1 (K), D63.1 (K), D65.1 (K), D67.1 (K), D69.1 (K), U1.22 (PD5)
ROW9: D62.1 (K), D64.1 (K), D66.1 (K), D68.1 (K), D70.1 (K), U1.21 (PD3)
SLOCK_IND: RLED3.2, U1.1 (PE6)
VCC: F1.2, U2.4 (VCC), USB1.2 (VBUS), USB1.11 (VBUS)
XTAL1: C3.1, U1.17 (XTAL1), Y1.1
XTAL2: C4.1, U1.16 (XTAL2), Y1.3

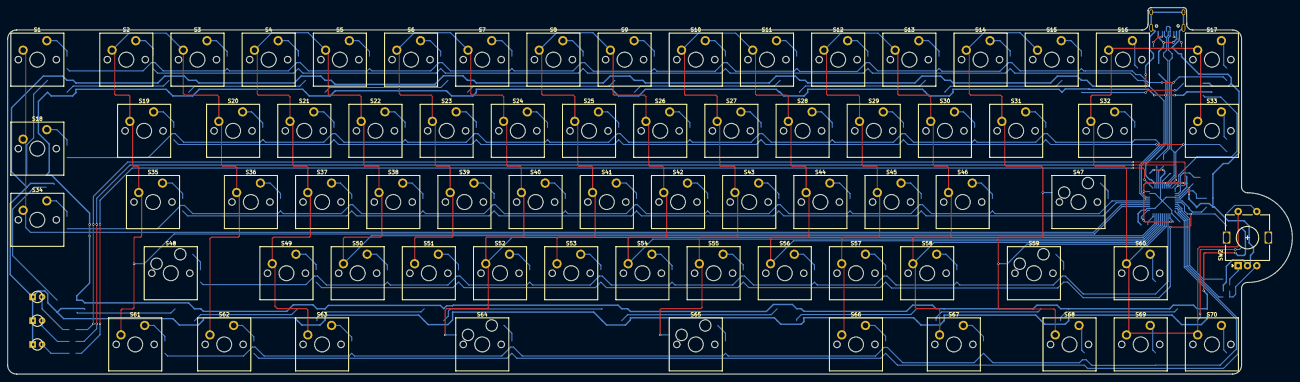
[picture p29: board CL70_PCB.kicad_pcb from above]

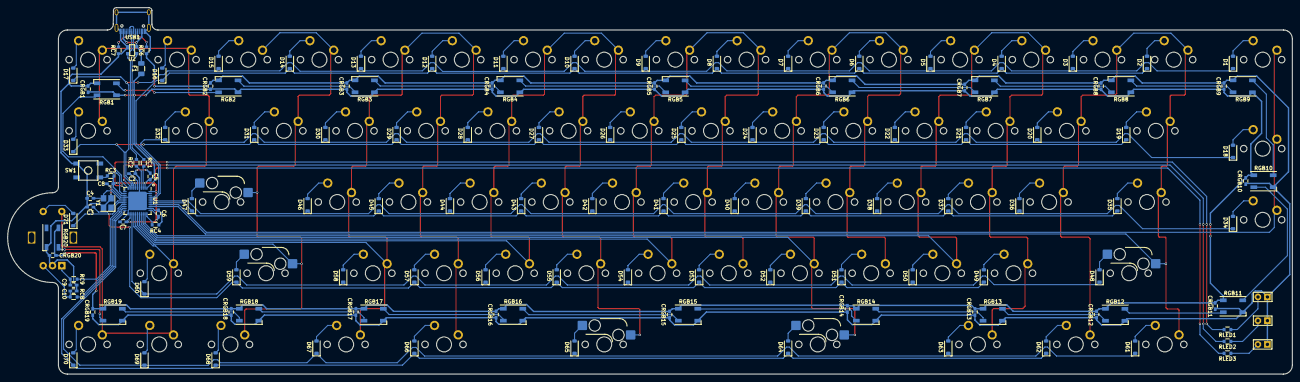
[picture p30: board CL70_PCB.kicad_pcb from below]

Board: 2 copper layers, 343.8 x 98.1 mm, 211 parts (137 on the bottom side), 134 nets.

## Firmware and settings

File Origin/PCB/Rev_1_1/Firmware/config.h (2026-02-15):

#pragma once

#define NKRO_DEFAULT_ON true

/* VIA related config */
#define VIA_EEPROM_LAYOUT_OPTIONS_SIZE 1
#define DYNAMIC_KEYMAP_LAYER_COUNT 4

/* Rotary Encoder related config */
#define ENCODER_A_PINS { D1 }
#define ENCODER_B_PINS { D2 }
#define ENCODER_MAP_KEY_DELAY 10

/* Layer Lock related config */
#define LAYER_INDICATOR_PIN B7
#define LAYER_LOCK_LAYER 3

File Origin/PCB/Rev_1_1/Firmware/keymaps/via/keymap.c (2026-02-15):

// Copyright 2023 QMK
// SPDX-License-Identifier: GPL-2.0-or-later

#include QMK_KEYBOARD_H

const uint16_t PROGMEM keymaps[][MATRIX_ROWS][MATRIX_COLS] = {
    [0] = LAYOUT(
        KC_ESC, KC_GRV, KC_1, KC_2, KC_3, KC_4, KC_5, KC_6, KC_7, KC_8, KC_9, KC_0, KC_MINS, KC_EQL, KC_BSLS, KC_DEL, KC_HOME, 
		KC_PGUP, KC_TAB, KC_Q, KC_W, KC_E, KC_R, KC_T, KC_Y, KC_U, KC_I, KC_O, KC_P, KC_LBRC, KC_RBRC, KC_BSPC, KC_END, 
		KC_PGDN, KC_LCTL, KC_A, KC_S, KC_D, KC_F, KC_G, KC_H, KC_J, KC_K, KC_L, KC_SCLN, KC_QUOT, KC_ENT, 
		KC_LSFT, KC_Z, KC_X, KC_C, KC_V, KC_B, KC_N, KC_M, KC_COMM, KC_DOT, KC_SLSH, KC_RSFT, KC_UP, KC_MUTE,
		MO(1), KC_LGUI, KC_LALT, KC_SPC, LT(1, KC_MPLY), LT(1, KC_RALT), LT(2, KC_RCTL), KC_LEFT, KC_DOWN, KC_RGHT
    ),
    [1] = LAYOUT(
        KC_TRNS, KC_TRNS, KC_F1, KC_F2, KC_F3, KC_F4, KC_F5, KC_F6, KC_F7, KC_F8, KC_F9, KC_F10, KC_F11, KC_F12, KC_TRNS, KC_TRNS, KC_TRNS, 
		KC_TRNS, KC_TRNS, KC_TRNS, KC_TRNS, KC_TRNS, KC_TRNS, KC_TRNS, KC_TRNS, KC_TRNS, KC_TRNS, KC_TRNS, KC_TRNS, KC_TRNS, KC_TRNS, KC_TRNS, KC_TRNS, 
		KC_TRNS, KC_TRNS, KC_TRNS, KC_TRNS, KC_TRNS, KC_TRNS, KC_TRNS, KC_TRNS, KC_TRNS, KC_TRNS, KC_TRNS, KC_TRNS, KC_TRNS, KC_TRNS, 
		KC_TRNS, KC_TRNS, KC_TRNS, KC_TRNS, KC_TRNS, KC_TRNS, KC_TRNS, KC_TRNS, KC_TRNS, KC_TRNS, KC_TRNS, KC_TRNS, KC_TRNS, KC_TRNS, 
		KC_TRNS, KC_TRNS, KC_TRNS, KC_TRNS, KC_TRNS, KC_TRNS, KC_TRNS, KC_TRNS, KC_TRNS, KC_TRNS
    )
};

#if defined(ENCODER_MAP_ENABLE)
const uint16_t PROGMEM encoder_map[][NUM_ENCODERS][NUM_DIRECTIONS] = {
    [0] = { ENCODER_CCW_CW(KC_VOLD, KC_VOLU)  },
    [1] = { ENCODER_CCW_CW(KC_BRID, KC_BRIU)  },
};
#endif

void keyboard_post_init_user(void) {
    gpio_set_pin_output(LAYER_INDICATOR_PIN);
}

layer_state_t layer_state_set_user(layer_state_t state) {
    if (layer_state_cmp(state, LAYER_LOCK_LAYER)) {
        gpio_write_pin_high(LAYER_INDICATOR_PIN);
    } else {
        gpio_write_pin_low(LAYER_INDICATOR_PIN);
    }
    return state;
}

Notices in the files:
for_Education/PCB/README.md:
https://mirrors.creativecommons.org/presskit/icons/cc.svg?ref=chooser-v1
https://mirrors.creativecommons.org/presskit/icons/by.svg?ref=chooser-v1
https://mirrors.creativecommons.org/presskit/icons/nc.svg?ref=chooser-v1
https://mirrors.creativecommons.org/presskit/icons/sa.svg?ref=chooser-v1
